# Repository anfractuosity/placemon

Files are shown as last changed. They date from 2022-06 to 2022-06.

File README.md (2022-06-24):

# placemon

The idea is to use the data collected from a number of sensors along with machine learning techniques to recognise different events occurring in your home.  For example processing audio data, to see if you have left a tap running.

One of the key inspirations is the paper - "Synthetic Sensors: Towards General-Purpose Sensing", I noticed some of the sensors used alone on their board such as the GridEye thermal sensor appear to be pretty expensive.  I've tried to select a smaller set of sensors that will hopefully allow us to achieve a similar level of accuracy at detecting different events.

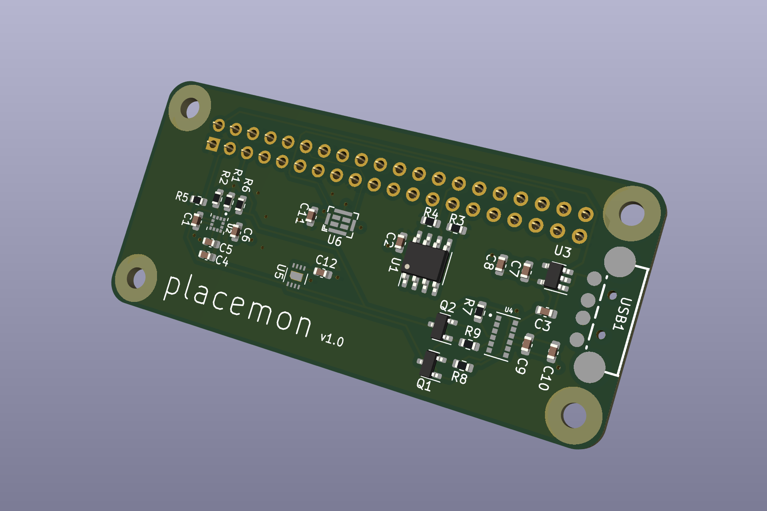
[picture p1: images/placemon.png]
3D Render


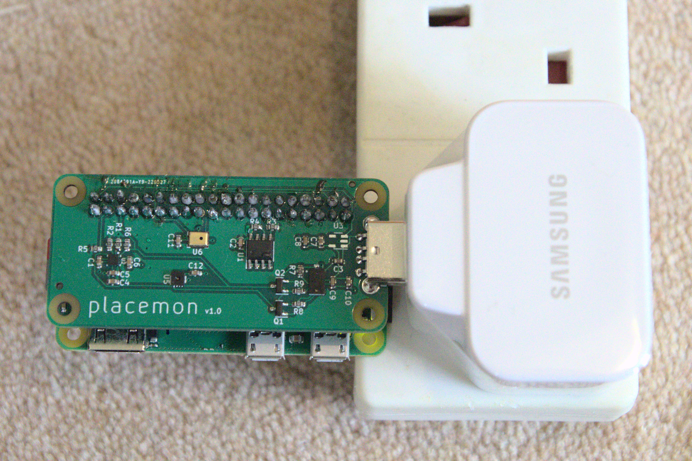
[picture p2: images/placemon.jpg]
Assembled


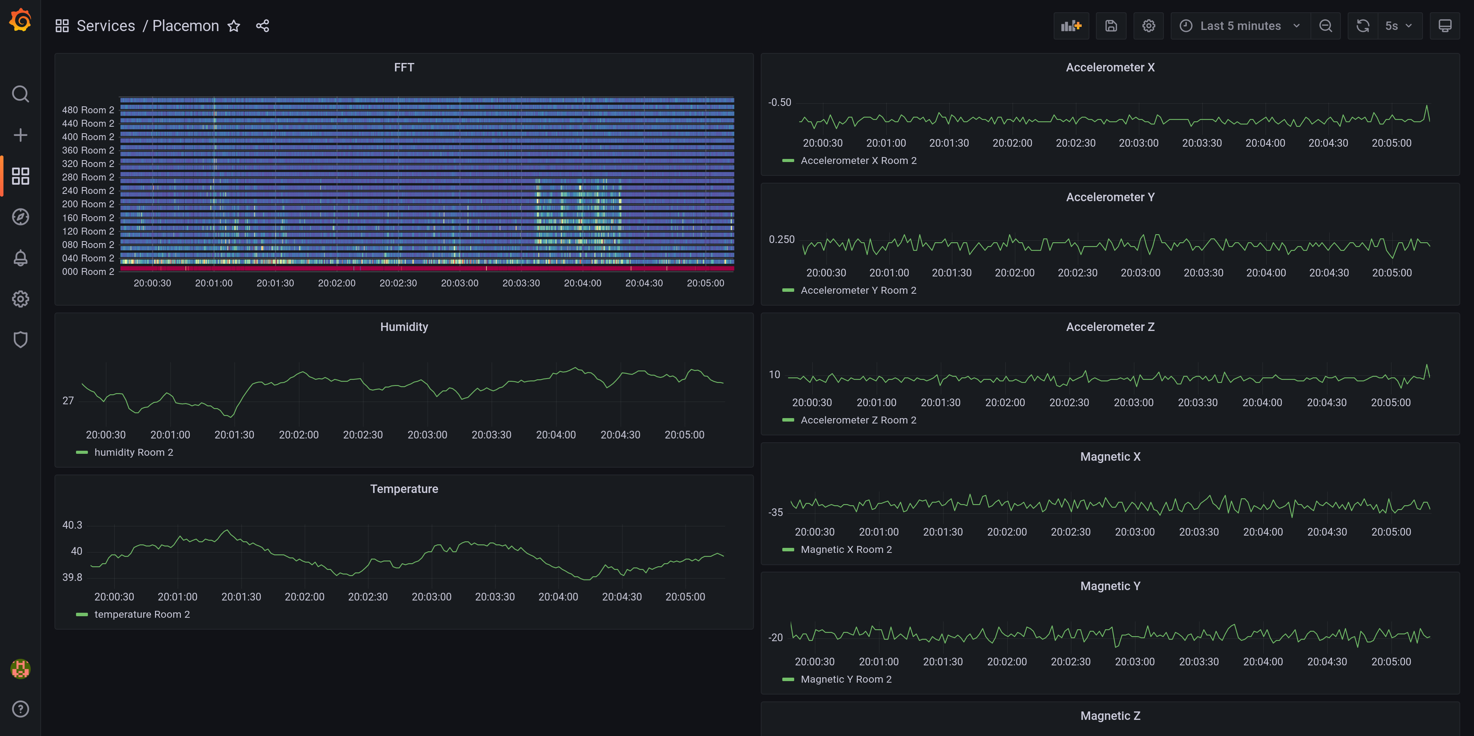
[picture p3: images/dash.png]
Grafana Dashboard


# Sensors

* LSM303AGR - accelerometer and compass
* SHT30-DIS - temperature and humidity sensor
* GMA4030H11-F26 - PDM microphone
* VL6180V1NR - Laser ToF sensor

# To Do

* Ooops - 2.54mm pin header is in slightly wrong location, so mounting holes won't be usable currently

# Testing

Install:

```
sudo apt install python3-pip
```

Libraries for microphone:
```
sudo apt install libasound2-dev libportaudio2 libsndfile1
pip3 install sounddevice soundfile
```

Libraries for temperature and accelerometer:
```
pip3 install adafruit-circuitpython-sht31d
pip3 install adafruit-circuitpython-lsm303-accel adafruit-circuitpython-lis2mdl
```

Run:
```
import board
import busio
import adafruit_sht31d
import adafruit_lsm303_accel
import adafruit_lis2mdl

i2c = board.I2C()
accel = adafruit_lsm303_accel.LSM303_Accel(i2c)
mag = adafruit_lis2mdl.LIS2MDL(i2c)
sensor = adafruit_sht31d.SHT31D(i2c)

print("Acceleration (m/s^2): X=%0.3f Y=%0.3f Z=%0.3f"%accel.acceleration)
print("Magnetometer (micro-Teslas)): X=%0.3f Y=%0.3f Z=%0.3f"%mag.magnetic)
print('Humidity: {0}%'.format(sensor.relative_humidity))
print('Temperature: {0}C'.format(sensor.temperature))
```

# Audio 

Uses PDM driver from https://github.com/imec-int/Raspberry-Pi-Installer-Scripts

Changed the following lines, to the suggestion:

```
/home/pi/Raspberry-Pi-Installer-Scripts/pdm_mic_module/linux_bcm2835_kernel/bcm2835-i2s.c:792:3: error: ‘struct snd_soc_dai_driver’ has no member named ‘symmetric_rates’; did you mean ‘symmetric_rate’?
/home/pi/Raspberry-Pi-Installer-Scripts/pdm_mic_module/linux_bcm2835_kernel/bcm2835-i2s.c:793:3: error: ‘struct snd_soc_dai_driver’ has no member named ‘symmetric_samplebits’; did you mean ‘symmetric_sample_bits’?
```

```
arecord --device="plughw:0,0" -f S16_LE -r 44100 out.wav
```

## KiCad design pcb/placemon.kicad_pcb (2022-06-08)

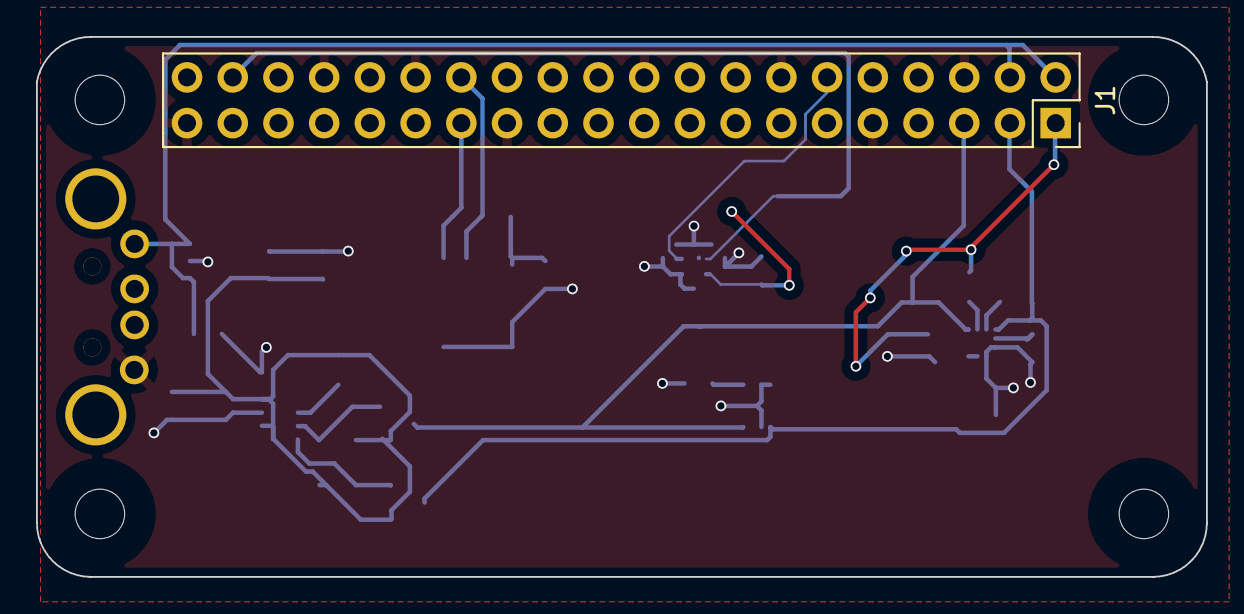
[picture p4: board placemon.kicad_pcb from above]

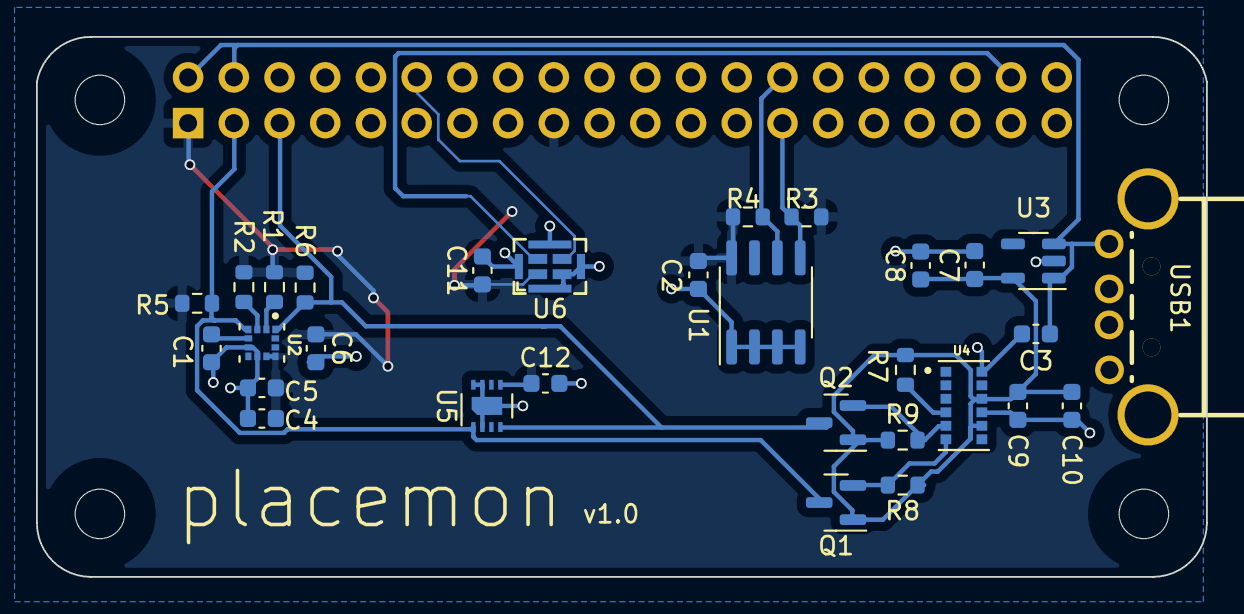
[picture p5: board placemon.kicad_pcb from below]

Board: 2 copper layers, 65.0 x 30.0 mm, 31 parts (30 on the bottom side), 16 nets.

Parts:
C1: 220nF; C_0603_1608Metric
C2: 100n; C_0603_1608Metric
C3, C4, C7: 10uF; C_0603_1608Metric
C5, C6, C9: 100nF; C_0603_1608Metric
C8, C11, C12: 0.1uF; C_0603_1608Metric
C10: 4.7uF; C_0603_1608Metric
J1: RPi_GPIO; PinSocket_2x20_P2.54mm_Vertical
Q1, Q2: BSS138; SOT-23
R1, R2: 10K; R_0603_1608Metric
R3, R4, R5, R6, R8, R9: 3.9K; R_0603_1608Metric
R7: 47K; R_0603_1608Metric
U1: CAT24C128; SOIC-8_3.9x4.9mm_P1.27mm
U2: LSM303AGR; PQFN50P200X200X100-12N
U3: LP5907MFX-2.8; SOT-23-5
U4: VL6180V1NR/1; XDCR_VL6180V1NR_1
U5: SHT30-DIS; Sensirion_DFN-8-1EP_2.5x2.5mm_P0.5mm_EP1.1x1.7mm
U6: GMA4030H11-F26
USB1: AM90; USB-AM-TH_AM90

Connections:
+2V8: C7.1, C8.1, C9.1, C10.1, Q1.1 (G), Q2.1 (G), R7.1, R8.1, R9.1, U3.5 (OUT), U4.8 (AVDD_VCSEL), U4.10 (AVDD)
+3V3: C2.1, C4.1, C5.1, C6.1, C11.1, C12.1, J1.1 (3.3V), J1.17 (3.3V), R1.1, R2.1, R3.1, R4.1, R5.1, R6.1, U1.8 (VCC), U2.9 (VDD), U2.10 (VDD_IO), U5.5 (VDD), U6.1 (VDD)
+5V: C3.1, J1.2 (5V), J1.4 (5V), U3.1 (IN), U3.3 (EN), USB1.1 (VCC)
GND: C1.2, C2.2, C3.2, C4.2, C5.2, C6.2, C7.2, C8.2, C9.2, C10.2, C11.2, C12.2, J1.6 (GND), J1.9 (GND), J1.14 (GND), J1.20 (GND), J1.25 (GND), J1.30 (GND), J1.34 (GND), J1.39 (GND), U1.1 (A0), U1.2 (A1), U1.3 (A2), U1.4 (GND), U2.6 (GND), U2.8 (GND), U3.2 (GND), U4.9 (AVSS_VCSEL), U4.12 (GND), U5.2 (ADDR), U5.7 (R), U5.8 (VSS), U5.9 (VSS), U6.2 (SELECT), U6.5 (GND), U6.6 (GND), U6.7 (GND), U6.8 (GND), USB1.4 (GND)
ID_SC: J1.28 (ID_SC), R4.2, U1.6 (SCL)
ID_SD: J1.27 (ID_SD), R3.2, U1.5 (SDA)
unnamed: C1.1, U2.5 (C1)
unnamed: R1.2, U2.2 (CS_XL)
unnamed: R2.2, U2.3 (CS_MAG)
unnamed: R7.2, U4.4 (GPIO0/CE)
SCK: J1.5 (GPIO03_SCL1_I2C), Q2.3 (D), R6.2, U2.1 (SCL/SPC), U5.4 (SCL)
SCK_2V8: Q2.2 (S), R9.2, U4.5 (SCL)
SDA: J1.3 (GPIO02_SDA1_I2C), Q1.3 (D), R5.2, U2.4 (SDA/SDI/SDO), U5.1 (SDA)
SDA_2V8: Q1.2 (S), R8.2, U4.6 (SDA)
clock: J1.12 (GPIO18), U6.3 (CLOCK)
data: J1.38 (GPIO20), U6.4 (DATA)

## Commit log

2022-06-08 Try to fix position of pin header
    [placemon.kicad_pcb]
2022-06-08 Fix horizontal position of pin header
    [placemon.kicad_pcb]
2022-06-08 Fix DRC issues
    [placemon.kicad_pcb]
